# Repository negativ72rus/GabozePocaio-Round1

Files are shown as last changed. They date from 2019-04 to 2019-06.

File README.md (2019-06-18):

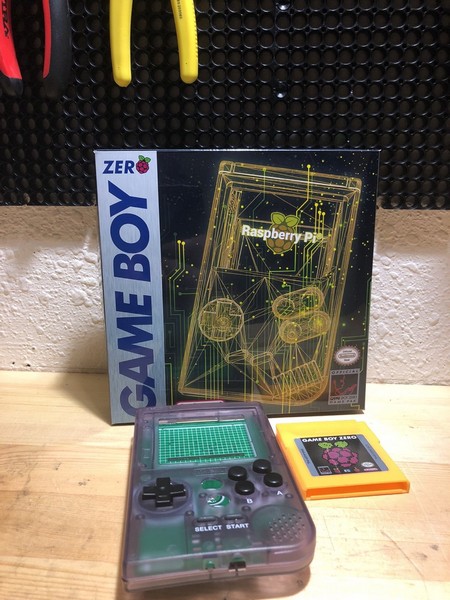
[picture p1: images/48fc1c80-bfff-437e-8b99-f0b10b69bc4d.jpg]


## Введение

### Gaboze Pocaio - Pocket All In One Remix
Это переработанная версия оригинального проекта [Gaboze Pocaio - Pocket All In One](https://github.com/32teeth/GabozePocaio-Round1)

Изменилось расположение кнопок, оно мне не нравилось в оригинальной плате. Теперь оно напоминает аркадные машины и геймпад sega Genesis.

### Особенности:

* 2.6" TFT LCD (ILI9342)
* Gameboy button layout interface (like the Sega Genesis)
* Raspberry Pi Zero
* Battery Charger (TP4056 Module)
* Headphone Jack (LM4857)
* Speaker capability (LM4857)

### Платформы:

Плата тестировалась на совместимость со следующими платформами:

- [x] [Emulation Station](http://www.emulationstation.org/)
- [x] [RetroPie](https://retropie.org.uk/)

### Разработка:

| Новый дизайн |
|:--:|
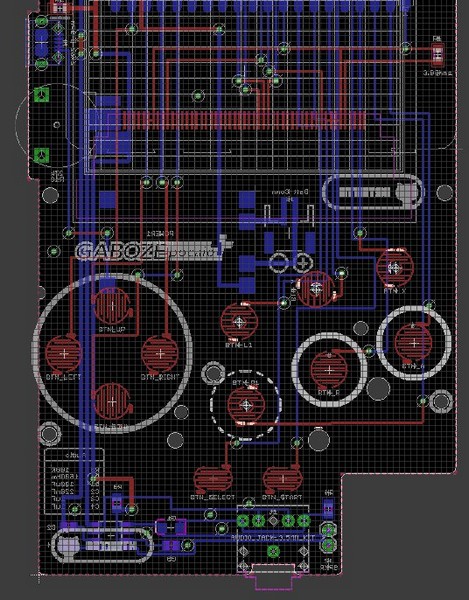
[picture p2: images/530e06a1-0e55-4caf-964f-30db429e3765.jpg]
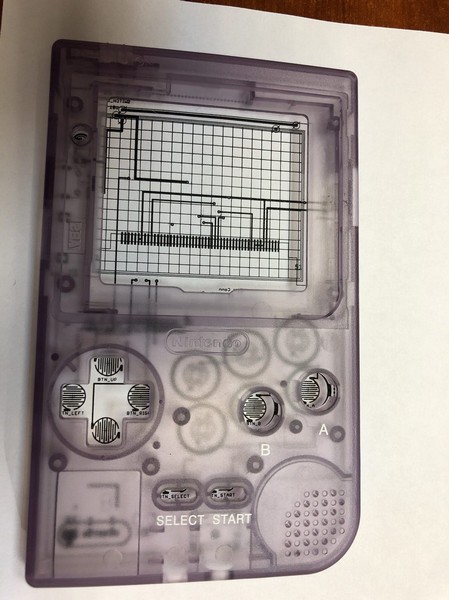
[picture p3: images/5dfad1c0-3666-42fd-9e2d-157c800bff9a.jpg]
|  |
| Готовые платы |
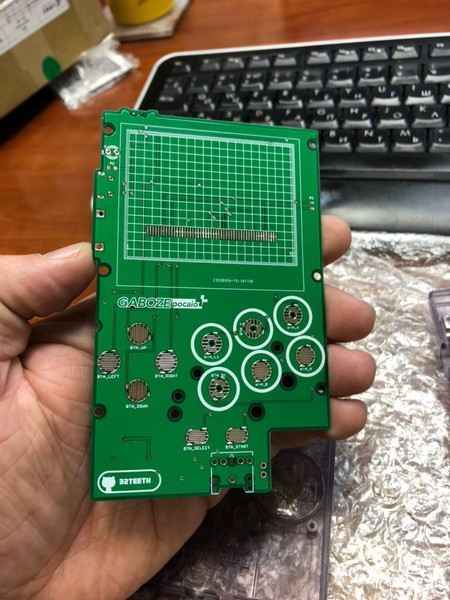
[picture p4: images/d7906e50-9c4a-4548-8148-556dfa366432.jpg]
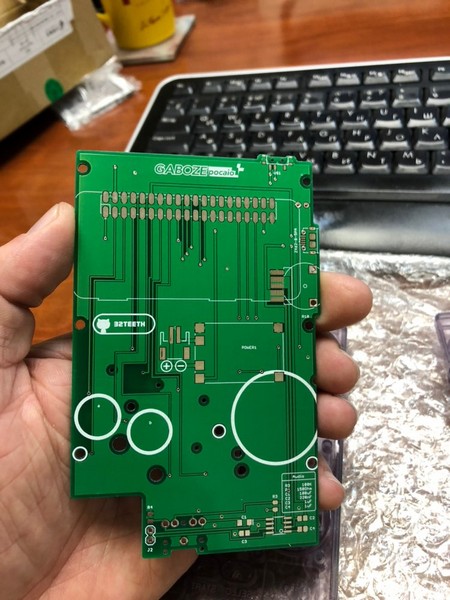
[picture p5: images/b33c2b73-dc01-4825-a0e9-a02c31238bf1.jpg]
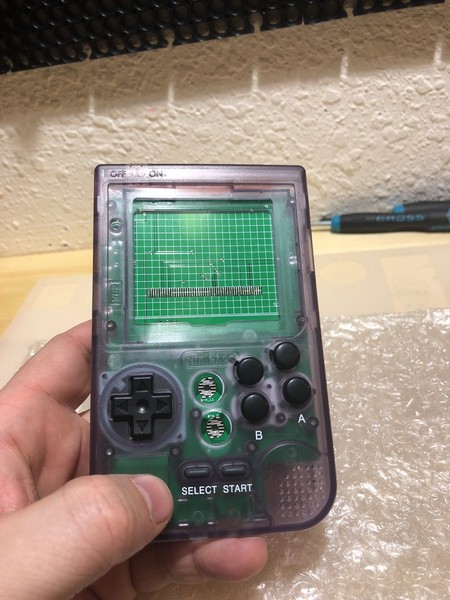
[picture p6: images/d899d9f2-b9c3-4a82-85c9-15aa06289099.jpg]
|   |
| Действующий прототип |
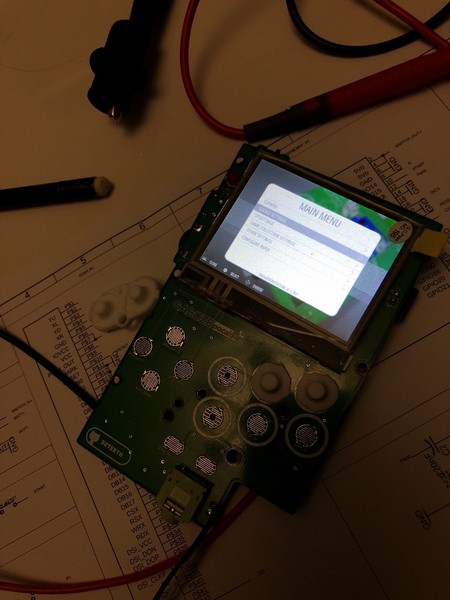
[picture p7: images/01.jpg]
| |
| Законченное устройство |
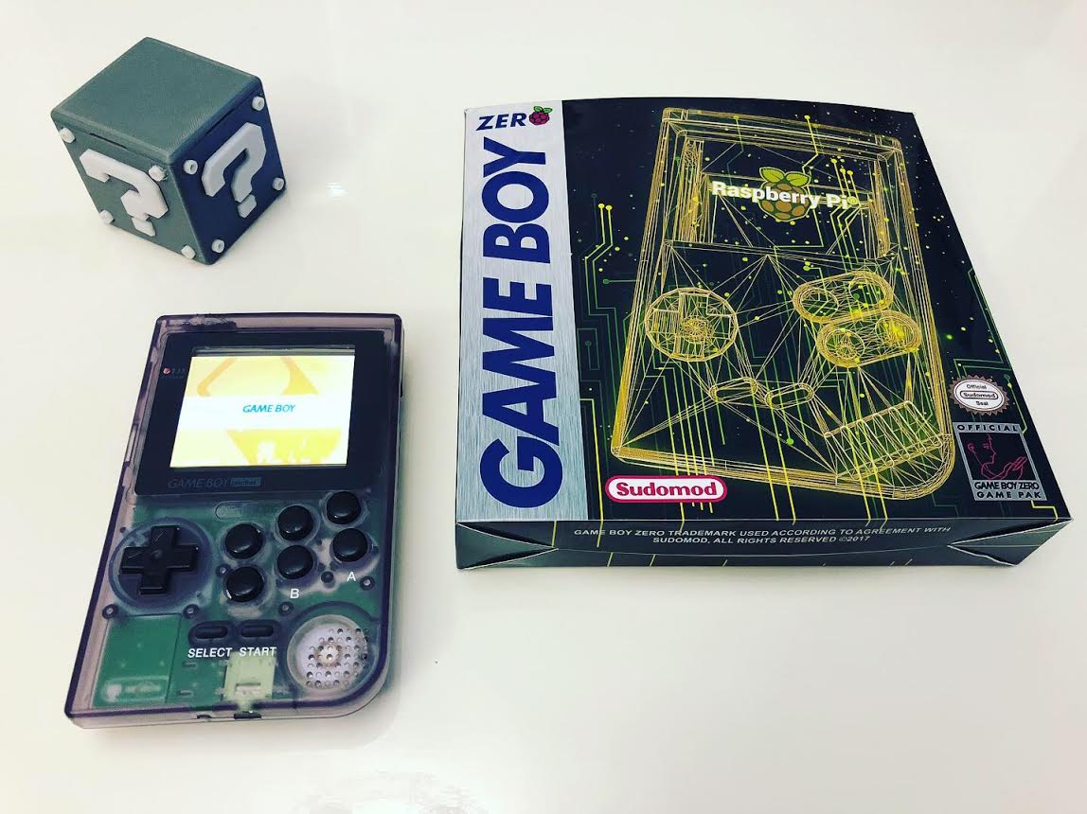
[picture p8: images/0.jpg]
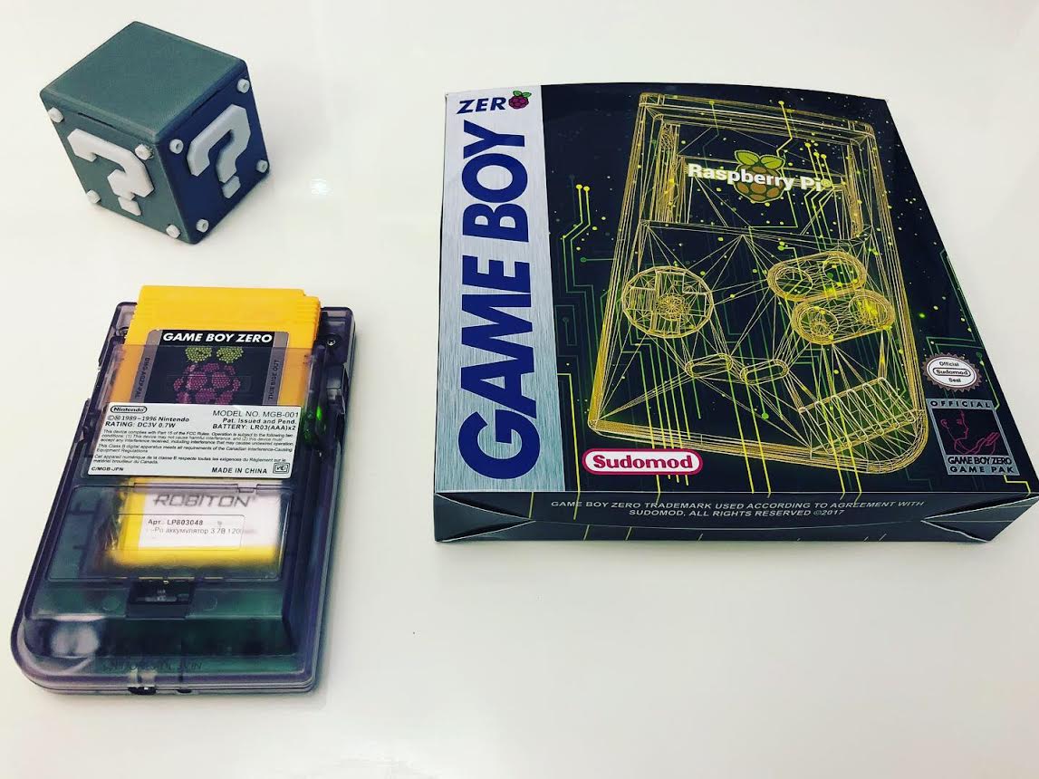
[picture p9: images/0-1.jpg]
|  |

## DIY
> Хотите собрать такой? Читайте [Wiki](https://github.com/32teeth/GabozePocaio-Round1/wiki/) на странице оригинального проекта

> `Gerber` файлы для заказа платы на производстве [тут](https://github.com/negativ72rus/GabozePocaio-Round1/tree/master/gerber)

> Список компонентов [тут](https://github.com/negativ72rus/GabozePocaio-Round1/tree/master/bom)

> Преднастроенный образ ОС можно [скачать тут](http://gameboy.32teeth.org/) (качать образ для PLUS версии)

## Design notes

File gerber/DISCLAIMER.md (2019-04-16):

### Notice
> Файлы `gerber` предоставляются "как есть", текущие изменения в схемотехнике вних могут быть не отражены.
>
> Они предоставляются бесплатно, в образовательных целях

-----

### Изображения платы

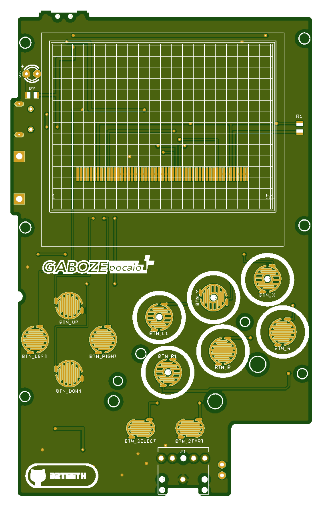
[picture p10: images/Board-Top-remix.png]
Board-Top
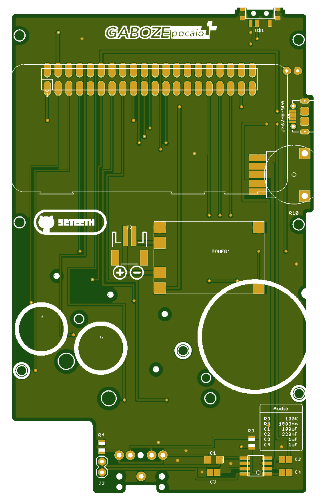
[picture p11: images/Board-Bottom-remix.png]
Board-Bottom
|  | |
|:--:|:--:|
| *Board Top* |*Board Bottom*|

Вы можете проверить их в [EasyEDA Gerber Viewer](https://jlcpcb.com/quote/gerberview/3f3f5ec0-e059-4040-932b-044b23d6642a_1_0_1_0_0.html) перед заказом

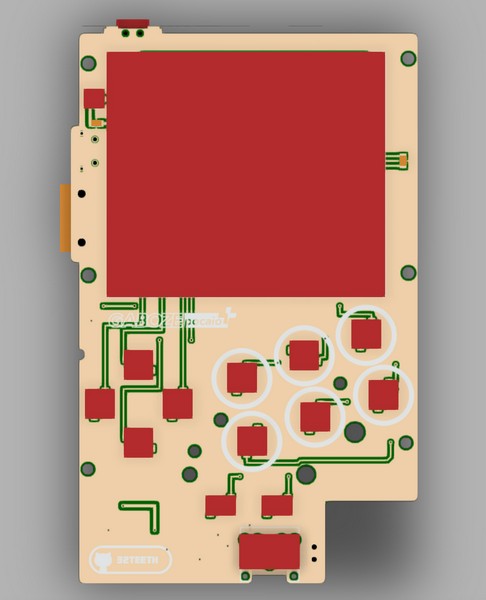
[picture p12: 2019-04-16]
images/Screenshot_18.jpg

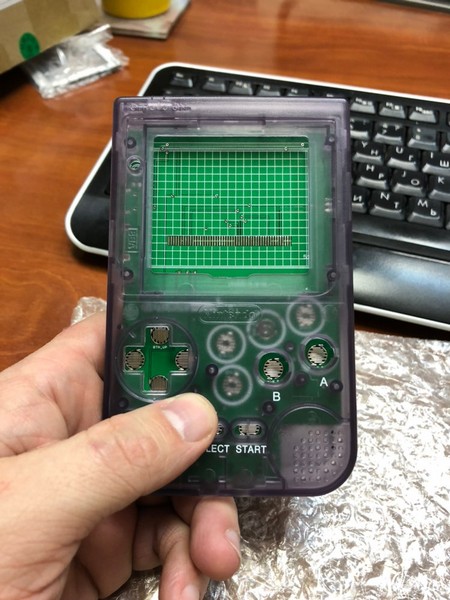
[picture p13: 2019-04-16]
images/22244ff9-26d0-499a-a4e7-e12591b27fe9.jpg

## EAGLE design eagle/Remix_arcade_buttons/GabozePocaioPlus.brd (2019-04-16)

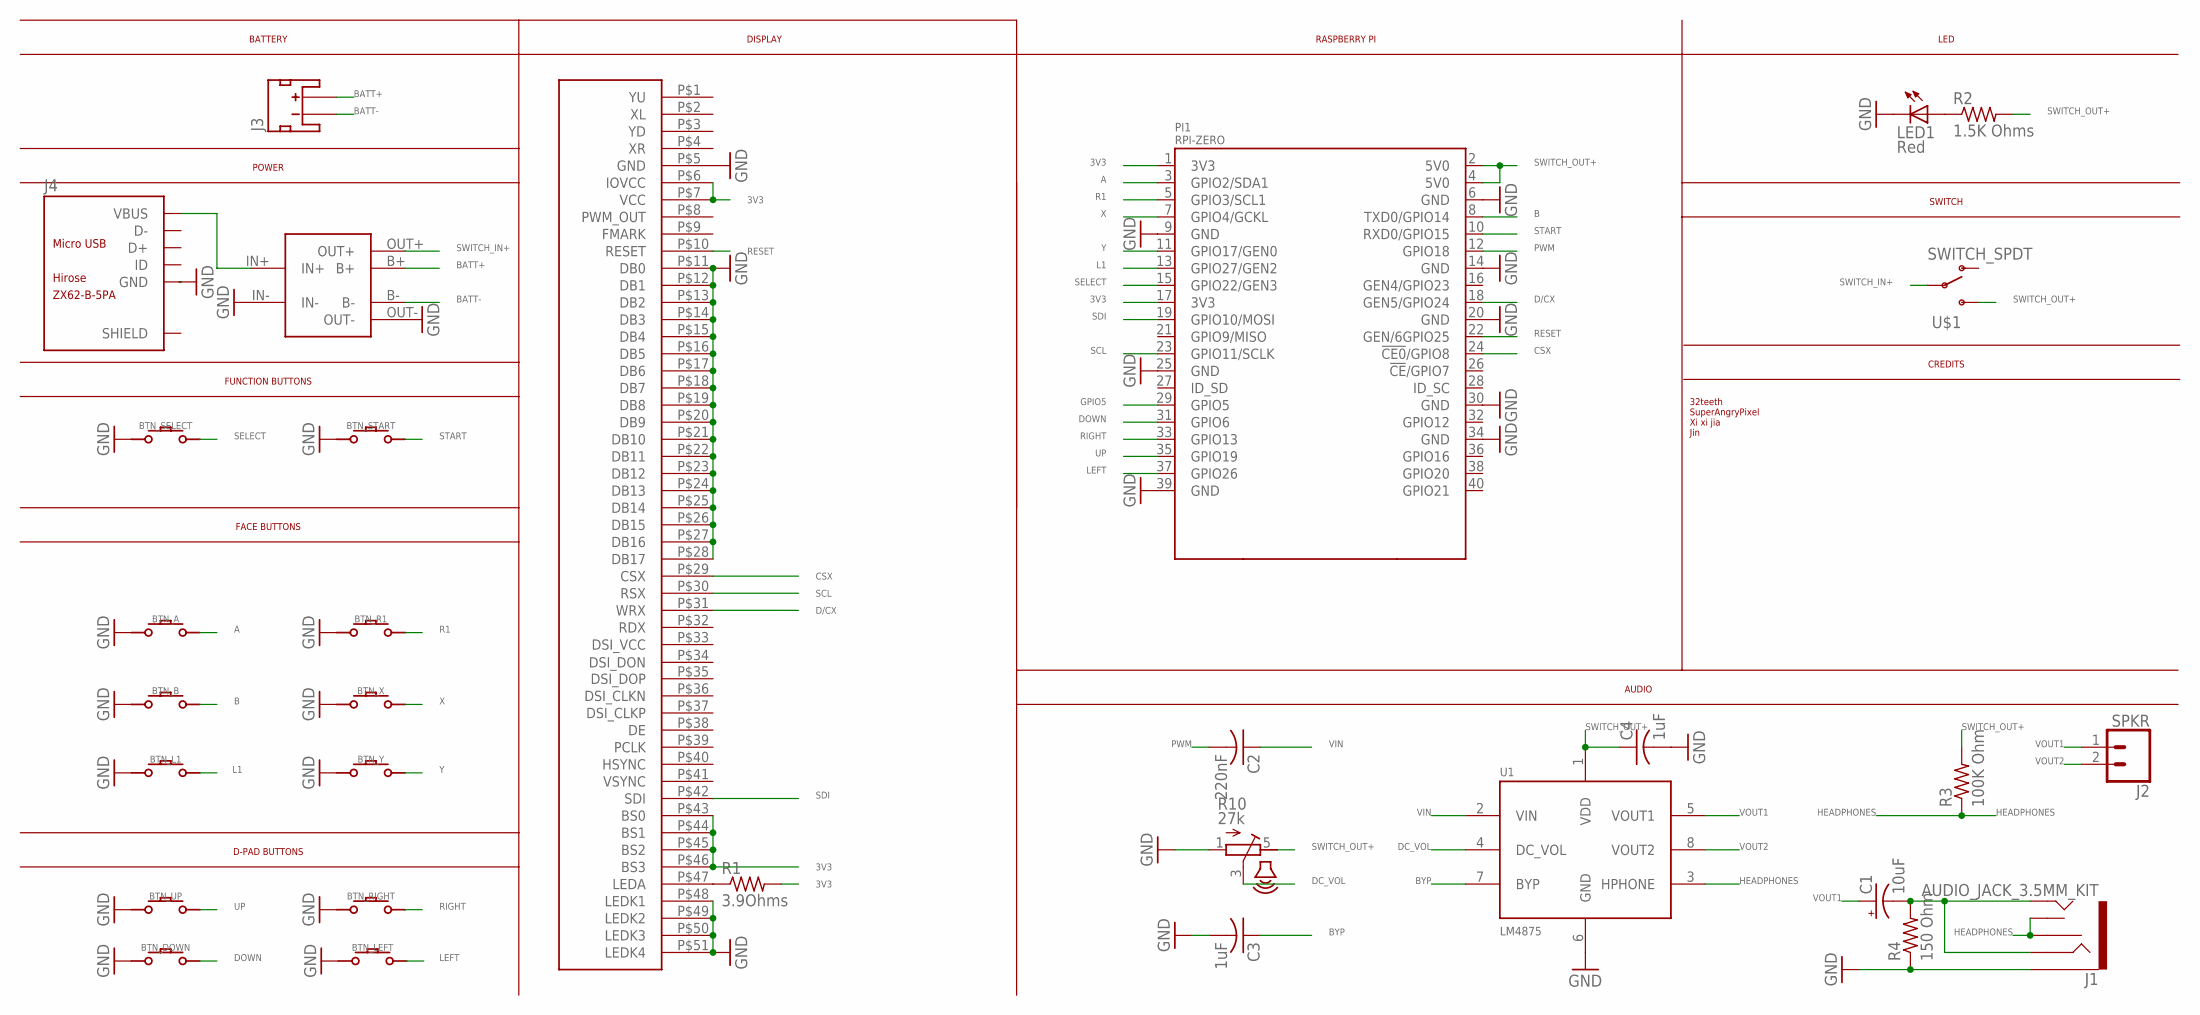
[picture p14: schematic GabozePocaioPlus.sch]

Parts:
BTN_A: CONDUCTIVE_BUTTON
BTN_B: CONDUCTIVE_BUTTON
BTN_DOWN: CONDUCTIVE_BUTTON
BTN_L1: CONDUCTIVE_BUTTON_DRILL
BTN_LEFT: CONDUCTIVE_BUTTON
BTN_R1: CONDUCTIVE_BUTTON_DRILL
BTN_RIGHT: CONDUCTIVE_BUTTON
BTN_SELECT: CONDUCTIVE_BUTTON_STARTSELECT
BTN_START: CONDUCTIVE_BUTTON_STARTSELECT
BTN_UP: CONDUCTIVE_BUTTON
BTN_X: CONDUCTIVE_BUTTON_DRILL
BTN_Y: CONDUCTIVE_BUTTON_DRILL
C1: 10uF; EIA3216
C2: 220nF; C0805
C3, C4: 1uF; C0805
J1: AUDIO_JACK_3.5MM_KIT; AUDIO-JACK-KIT
J2: SPKR; 1X02
J3: Batt Conn; JST-2-SMD
J4: ZX62-B-5PA; MICRO-USB5+6P-SMD-0.65-AB
LED1: Red; LED3MM
PI1: RPI-ZERO
POWER1: 03962A
R1: 3.9Ohms; R0805
R2: 1.5K Ohms; R0805
R3: 100K Ohm; R0805
R4: 150 Ohm; R0805
R10: 27k; VOLUME
U1: LM4875; SOIC8
U$1: SWITCH_SPDT; KPS-1290
U$2: TFT-DISPLAY-2.6-51PIN

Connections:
3V3: PI1.1 (3V3), PI1.17 (3V3), R1.2, U$2.P$6 (IOVCC), U$2.P$7 (VCC), U$2.P$43 (BS0), U$2.P$44 (BS1), U$2.P$45 (BS2), U$2.P$46 (BS3)
A: BTN_A.P$ACTIVE, PI1.3 (GPIO2/SDA1)
B: BTN_B.P$ACTIVE, PI1.8 (TXD0/GPIO14)
BATT+: J3.2 (+), POWER1.B+
BATT-: J3.1 (-), POWER1.B-
BYP: C3.1, U1.7 (BYP)
CSX: PI1.24 (!CE0!/GPIO8), U$2.P$29 (CSX)
D/CX: PI1.18 (GEN5/GPIO24), U$2.P$31 (WRX)
DC_VOL: R10.3 (S), U1.4 (DC_VOL)
DOWN: BTN_DOWN.P$ACTIVE, PI1.31 (GPIO6)
GND: BTN_A.P$GND, BTN_B.P$GND, BTN_DOWN.P$GND, BTN_L1.P$GND, BTN_LEFT.P$GND, BTN_R1.P$GND, BTN_RIGHT.P$GND, BTN_SELECT.P$GND, BTN_START.P$GND, BTN_UP.P$GND, BTN_X.P$GND, BTN_Y.P$GND, C3.2, C4.2, J1.SLEEVE, J4.5 (GND), LED1.K (C), PI1.6 (GND), PI1.9 (GND), PI1.14 (GND), PI1.20 (GND), PI1.25 (GND), PI1.30 (GND), PI1.34 (GND), PI1.39 (GND), POWER1.IN-, POWER1.OUT-, R4.1, R10.1 (A), U1.6 (GND), U$2.P$5 (GND), U$2.P$11 (DB0), U$2.P$12 (DB1), U$2.P$13 (DB2), U$2.P$14 (DB3), U$2.P$15 (DB4), U$2.P$16 (DB5), U$2.P$17 (DB6), U$2.P$18 (DB7), U$2.P$19 (DB8), U$2.P$20 (DB9), U$2.P$21 (DB10), U$2.P$22 (DB11), U$2.P$23 (DB12), U$2.P$24 (DB13), U$2.P$25 (DB14), U$2.P$26 (DB15), U$2.P$27 (DB16), U$2.P$28 (DB17), U$2.P$48 (LEDK1), U$2.P$49 (LEDK2), U$2.P$50 (LEDK3), U$2.P$51 (LEDK4)
GPIO5: PI1.29 (GPIO5)
HEADPHONES: J1.RSH, J1.TSH, R3.1, U1.3 (HPHONE)
L1: BTN_L1.P$ACTIVE, PI1.13 (GPIO27/GEN2)
LED: LED1.A, R2.1
LEFT: BTN_LEFT.P$ACTIVE, PI1.37 (GPIO26)
unnamed: R1.1, U$2.P$47 (LEDA)
PWM: C2.2, PI1.12 (GPIO18)
R1: BTN_R1.P$ACTIVE, PI1.5 (GPIO3/SCL1)
RESET: PI1.22 (GEN/6GPIO25), U$2.P$10 (RESET)
RIGHT: BTN_RIGHT.P$ACTIVE, PI1.33 (GPIO13)
SCL: PI1.23 (GPIO11/SCLK), U$2.P$30 (RSX)
SDI: PI1.19 (GPIO10/MOSI), U$2.P$42 (SDI)
SELECT: BTN_SELECT.P$ACTIVE, PI1.15 (GPIO22/GEN3)
START: BTN_START.P$ACTIVE, PI1.10 (RXD0/GPIO15)
SWITCH_IN+: POWER1.OUT+, U$1.P
SWITCH_OUT+: C4.1, PI1.2 (5V0), PI1.4 (5V0), R2.2, R3.2, R10.5 (E), U1.1 (VDD), U$1.S
UP: BTN_UP.P$ACTIVE, PI1.35 (GPIO19)
VIN: C2.1, U1.2 (VIN)
VIN1: C1.-, J1.RING, J1.TIP, R4.2
VOUT1: C1.+, J2.1, U1.5 (VOUT1)
VOUT2: J2.2, U1.8 (VOUT2)
VUSB: J4.1 (VBUS), POWER1.IN+
X: BTN_X.P$ACTIVE, PI1.7 (GPIO4/GCKL)
Y: BTN_Y.P$ACTIVE, PI1.11 (GPIO17/GEN0)

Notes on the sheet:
D-PAD BUTTONS
FACE BUTTONS
FUNCTION BUTTONS
POWER
BATTERY
SWITCH
LED
DISPLAY
RASPBERRY PI
AUDIO
CREDITS
32teeth SuperAngryPixel Xi xi jia Jin

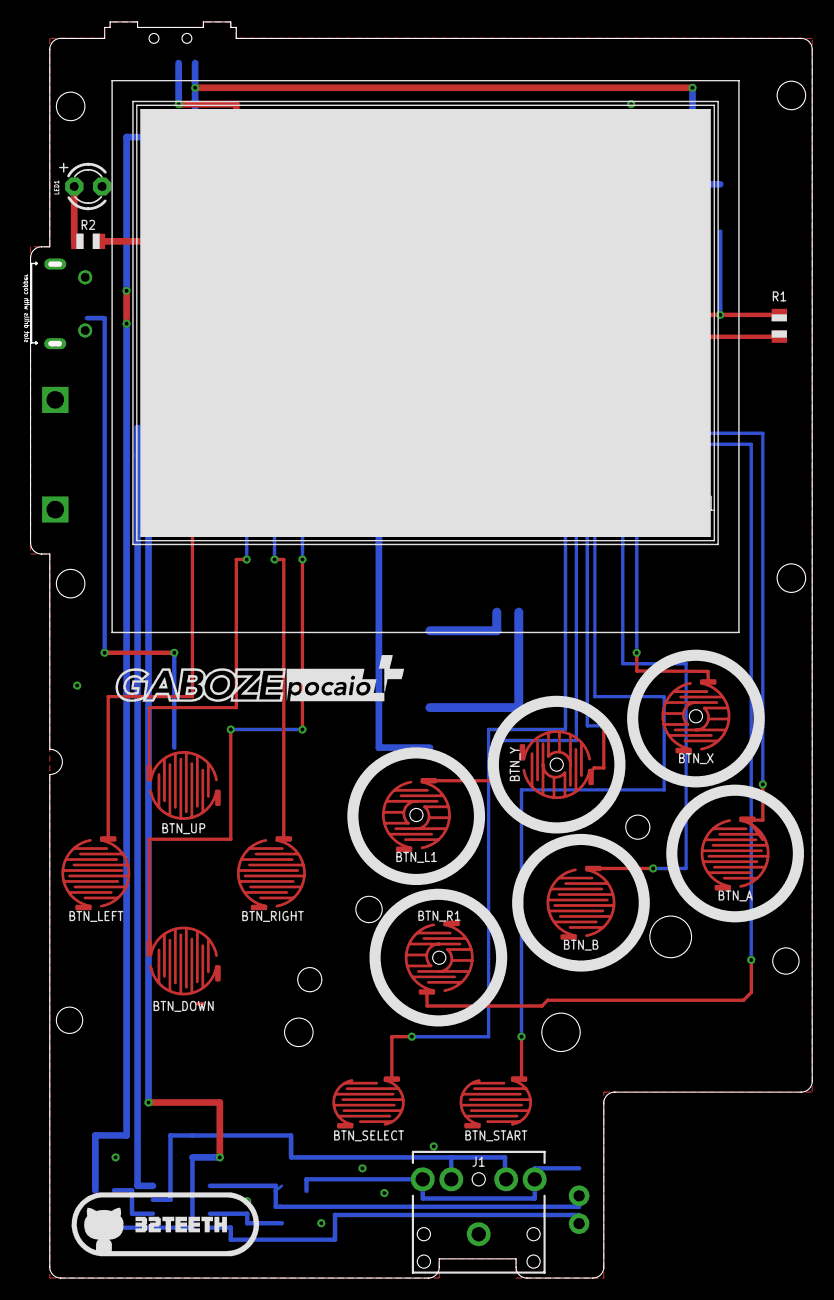
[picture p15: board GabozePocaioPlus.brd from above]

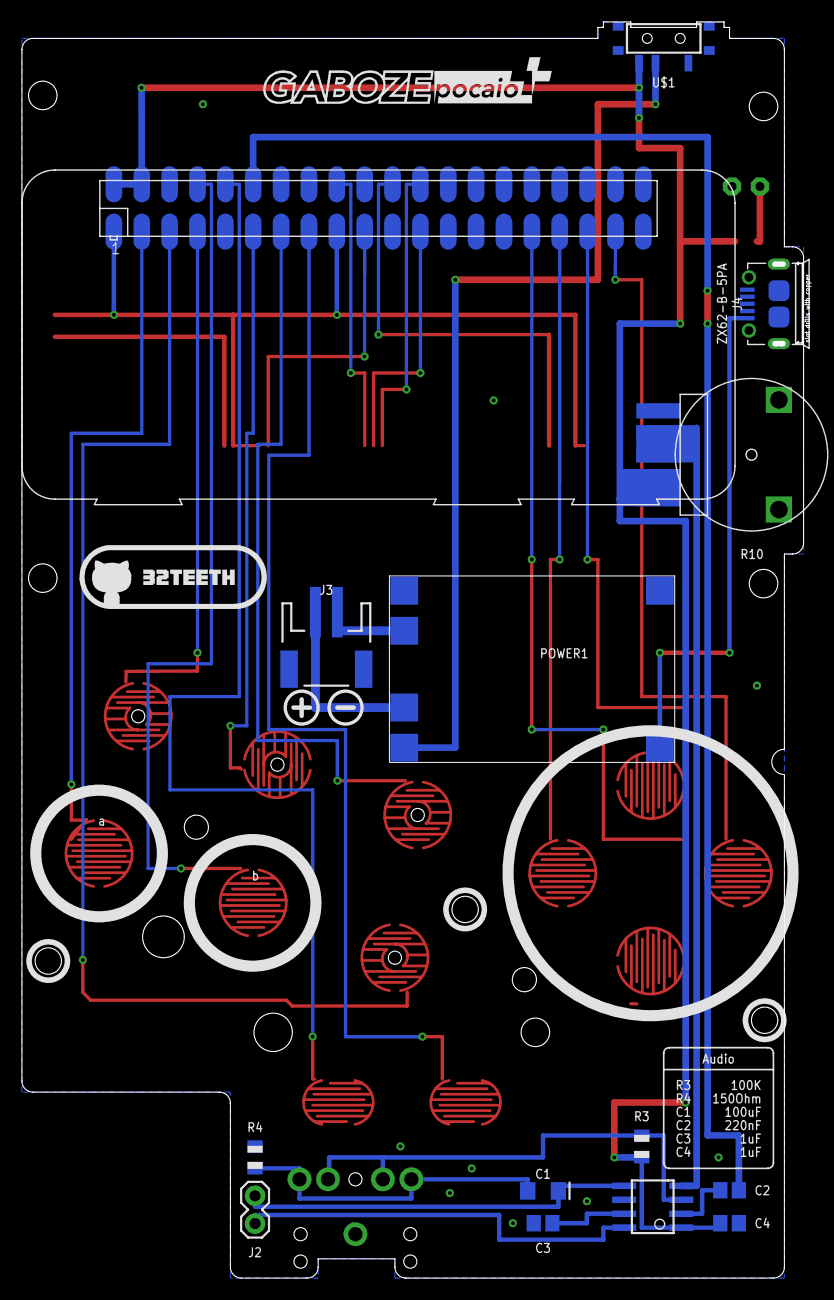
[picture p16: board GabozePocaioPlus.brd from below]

Board: 2 copper layers, 71.2 x 114.5 mm, 31 parts (14 on the bottom side), 34 nets.

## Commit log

2019-04-16 добавлен ремикс платы
    [GabozePocaioPlus.brd, GabozePocaioPlus.sch]
2019-04-16 Create outputs.rar
    Гербер ремикса платы
2019-04-16 зачистка
    [GabozePocaio-Extension-Aux.GBL, GabozePocaio-Extension-Aux.GBO, GabozePocaio-Extension-Aux.GBP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]
2019-04-16 обновлены изображения плат
2019-04-16 изображения
2019-04-16 новые фото разработки
2019-04-16 ресайз фото

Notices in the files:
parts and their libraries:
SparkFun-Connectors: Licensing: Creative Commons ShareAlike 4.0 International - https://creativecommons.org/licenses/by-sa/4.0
